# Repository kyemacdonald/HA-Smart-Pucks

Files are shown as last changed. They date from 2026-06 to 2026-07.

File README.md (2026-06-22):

# HA-Smart-Pucks
Home Assistant Smart Speakers based on ESP32s running ESPhome

<h2>Very much early stage. Use at own risk.</h2>

Smart Puck - HA Voice Assistant
* ESP32 S3 N16R8 / N8R2
* MAX98357A Class D Amplifier
* INMP441 Omnidirection Mic
* 5V WS2812 24LED ring (outer diameter 72mm)
* 2" 4 Ohm 3W speaker

Smart Speaker Box - HA Voice Assistant + SendSpin endpoint
* ESP32 S3 N16R8 
* MAX98357A Class D Amplifier
* INMP441 Omnidirection Mic
* 5V WS2812 8LED ring (outer diameter 27mm)
* 2" 4 Ohm 3W speaker
* PCM5102A DAC

Smart Puck

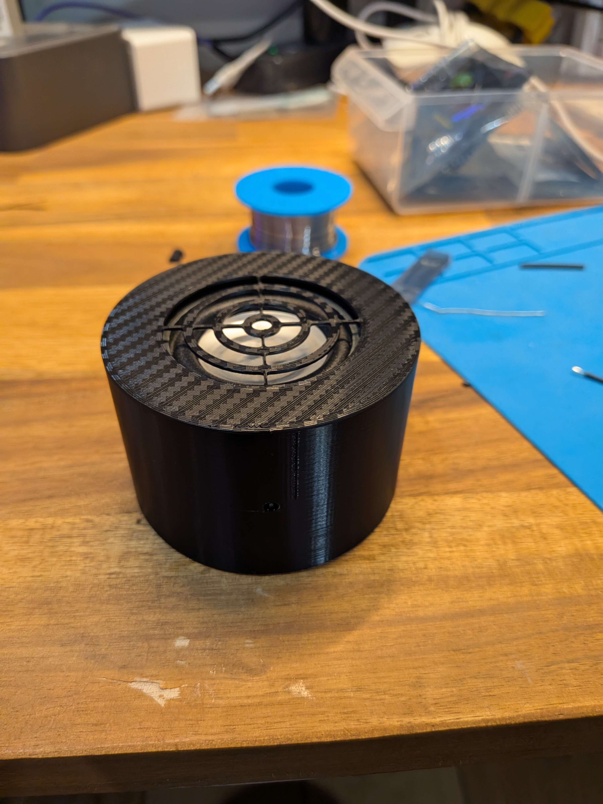
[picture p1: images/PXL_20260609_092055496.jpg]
Smart Puck


Smart Speaker Box

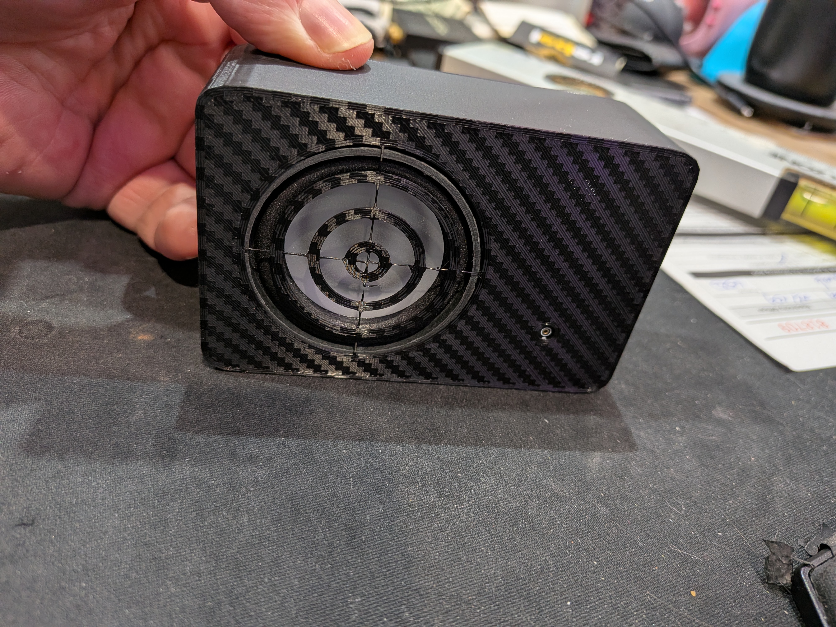
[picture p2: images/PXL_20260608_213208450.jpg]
Smart Speaker Box


Wiring Diagram for the Puck
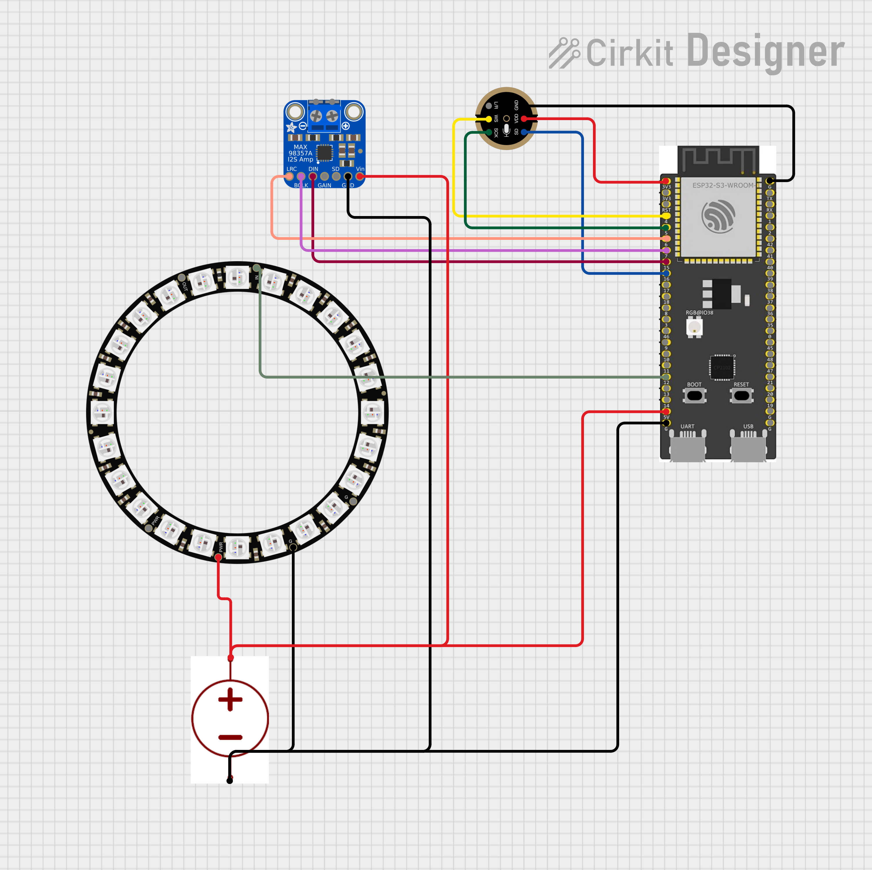
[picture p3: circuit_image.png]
Circuit Image


Wiring Diagram for the Box
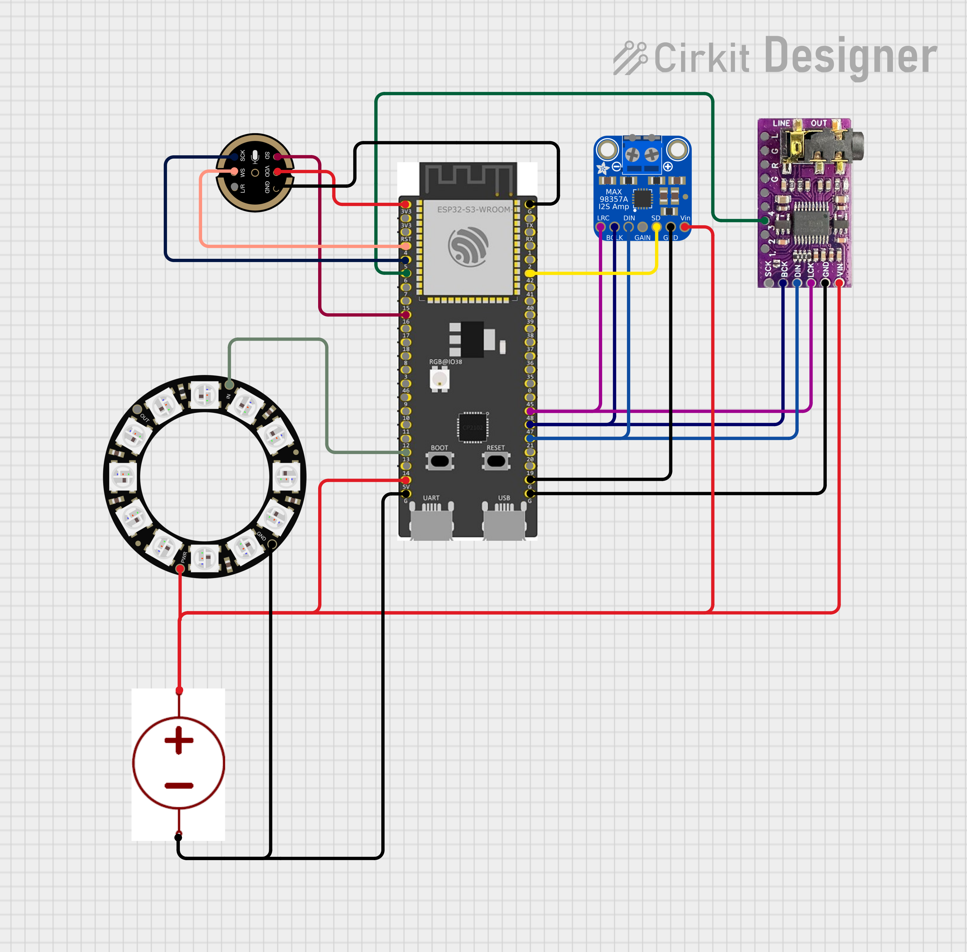
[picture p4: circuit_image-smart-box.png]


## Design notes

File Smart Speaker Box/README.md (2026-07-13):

Smart Speaker Box

Due to limitations in ESP hardware it is not possible to have more than 2 I2S devices connected.  One of these has to be the microphone and as a result only 1 channel can be used for DACs to allow output.

In order to get past this limitation both DACs are connected to the same pins on the ESP and they are individually muted depending on requirements.  Media playback goes via the PCM 3.5mm dac and TTS / announcements are routed via the MAX and internal 2" speaker.

There are some limitations to this setup.  Media is streamed to the device and uses the built in mixer system to queue playback.  TTS / Announce is given priority, which means it will interupt media playback and then media playback will resume.  There are however multiple buffers in the audio stream, their exact size is variable and there is no flag for when the buffers exhaust. As such you will get media output via the 2" internal speaker for a period before the TTS starts.  This ranges from sub 50ms to a second.  I have not been able to find a solution to this.  There is occasionally a small pop at the end of TTS before it switches back to the PCM.

The design setup is intended for 100% volume on both DACs.  This is a suitable volume level for the TTS output.  Adding it as a variable will likely happen in the future.

Finally SendSpin is very CPU intensive, you need to specify that the player receives PCM output from MusicAssistant otherwise CPU will get overwhelmed and you will lose wakeword detection.  There is occasional audio corruption when playback first starts, transient for up to 2 seconds.  This is all caused by CPU bind.  

13/7/26 Update
Added timer support.  You will need the timer_done.mp3 and place into an audio directory under esphome

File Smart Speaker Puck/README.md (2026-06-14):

STL files for the puck

Base and led support ring are universal.  

Lid with LED cutout plus diffuser is suitable for dark filament.

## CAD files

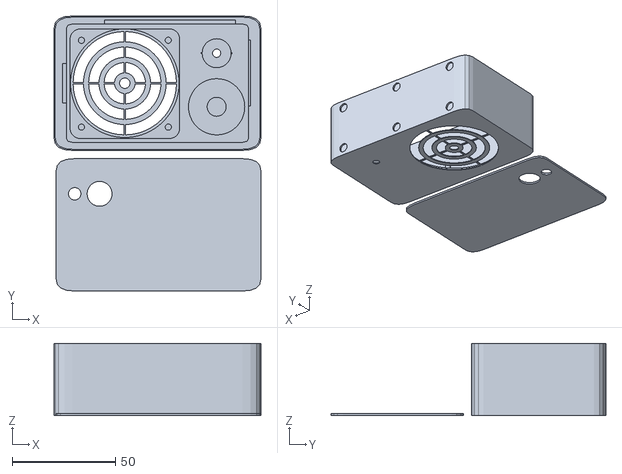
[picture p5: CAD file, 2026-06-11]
Smart Speaker Box/Smart Box.stl
100.0 x 133.0 x 35.0

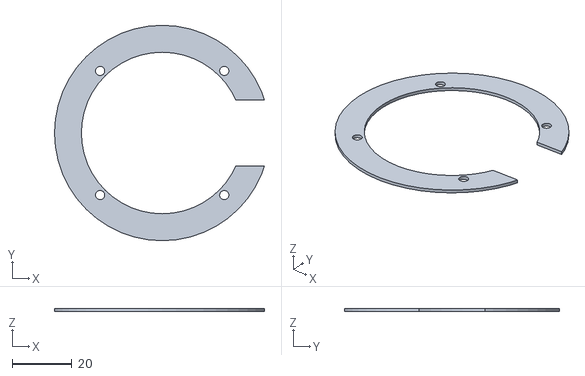
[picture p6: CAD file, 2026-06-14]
Smart Speaker Puck/Smark Puck LED support ring.stl
70.2 x 72.0 x 1.00

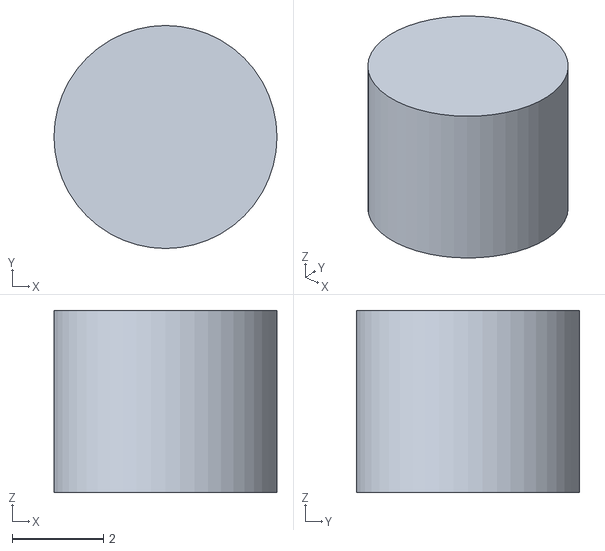
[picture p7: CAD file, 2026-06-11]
Smart Speaker Box/Feet.stl
4.90 x 4.90 x 4.00

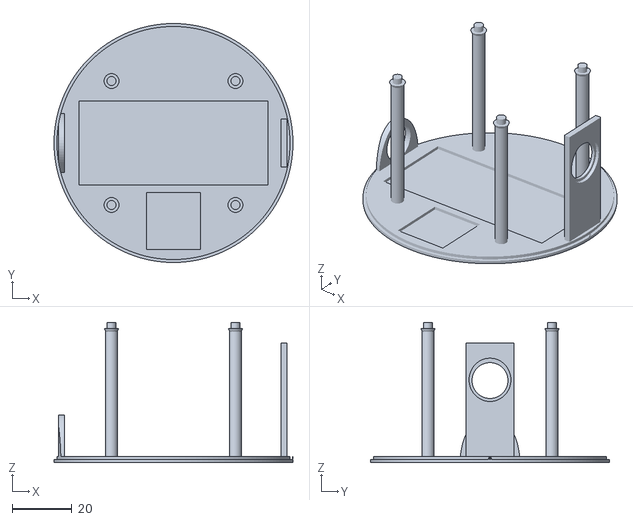
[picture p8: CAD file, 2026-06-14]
Smart Speaker Puck/Smart Puck V2.stl
80.0 x 80.0 x 47.0

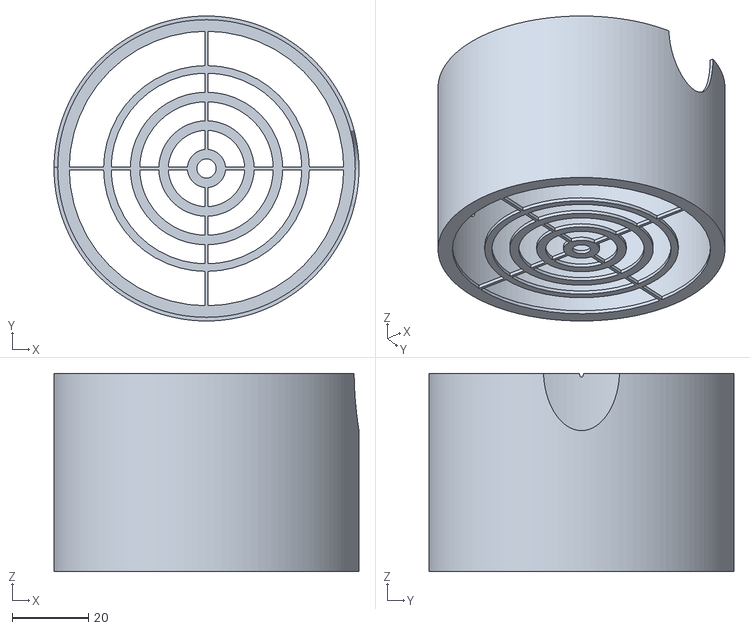
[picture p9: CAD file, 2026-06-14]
Smart Speaker Puck/Puck V2 Top.stl
80.0 x 80.0 x 52.0

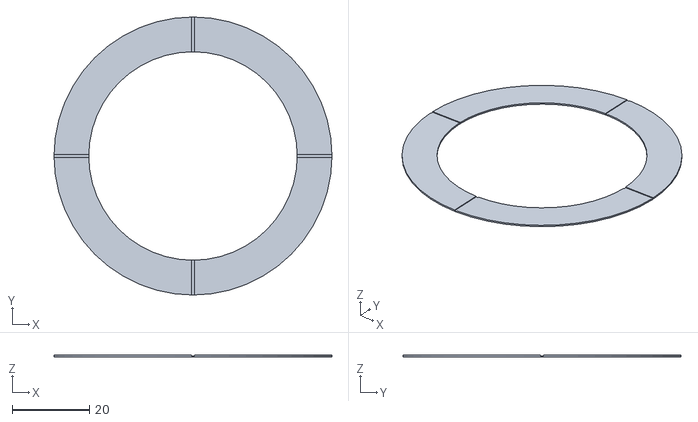
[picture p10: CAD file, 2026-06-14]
Smart Speaker Puck/Puck LED Diffuser.stl
72.0 x 72.0 x 0.4

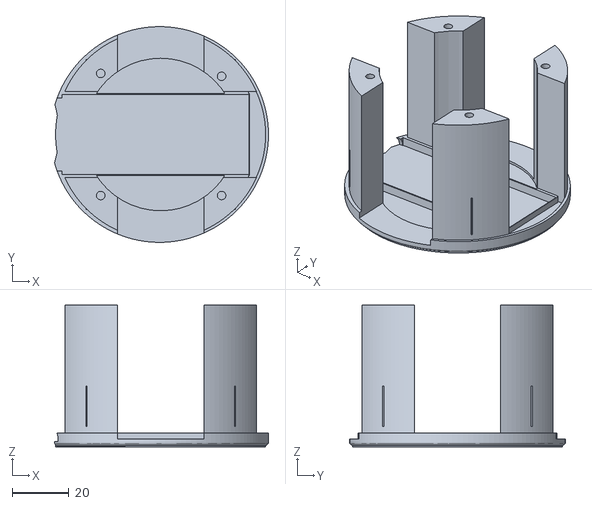
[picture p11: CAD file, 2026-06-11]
Smart Speaker Puck/Speaker puck base - tall.stl
75.4 x 76.0 x 50.0

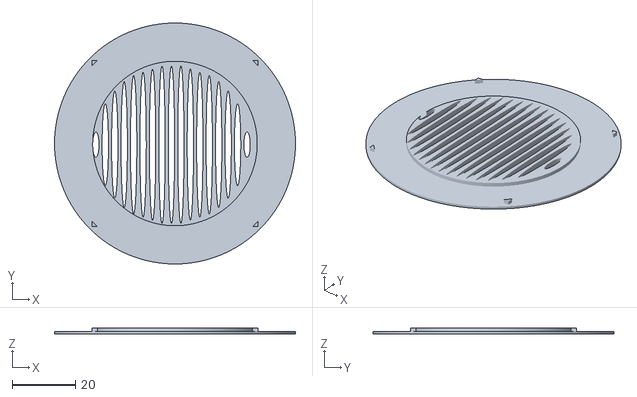
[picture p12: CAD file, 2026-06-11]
Smart Speaker Puck/Speaker-Puck-lid.stl
76.5 x 76.5 x 2.00

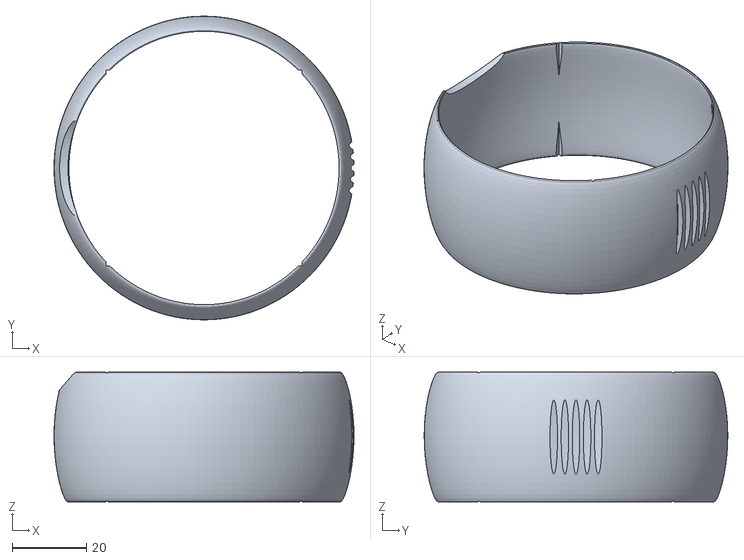
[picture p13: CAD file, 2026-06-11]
Smart Speaker Puck/Speaker-puck-walls.stl
81.0 x 82.0 x 35.0

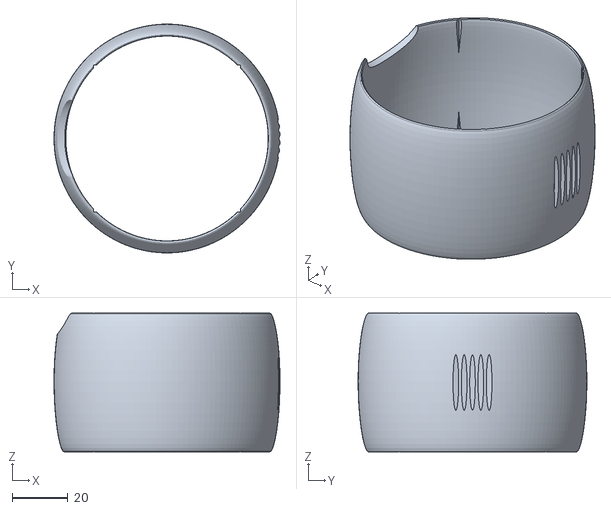
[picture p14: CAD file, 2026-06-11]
Smart Speaker Puck/Speaker puck walls - tall.stl
81.4 x 82.4 x 50.0

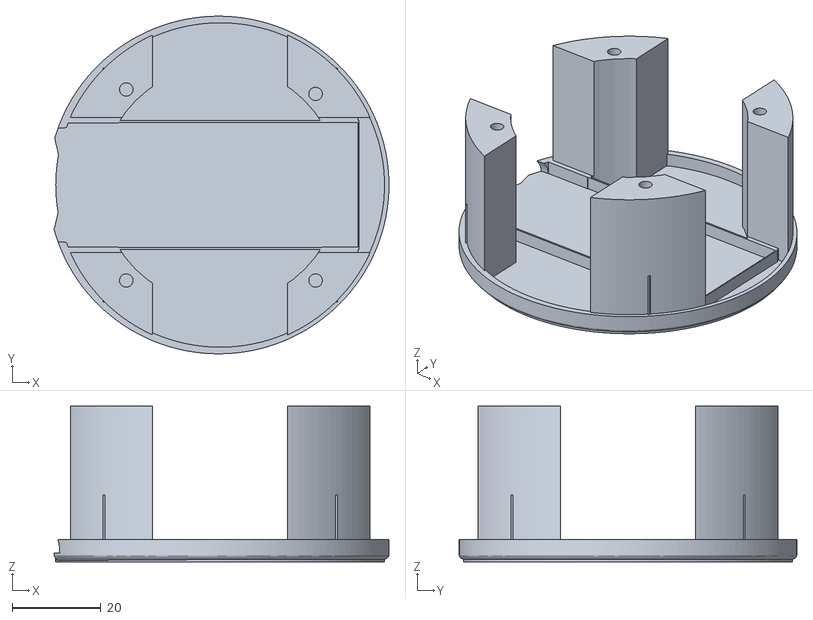
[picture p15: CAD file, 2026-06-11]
Smart Speaker Puck/Speaker-puck-base.stl
75.4 x 76.0 x 35.0

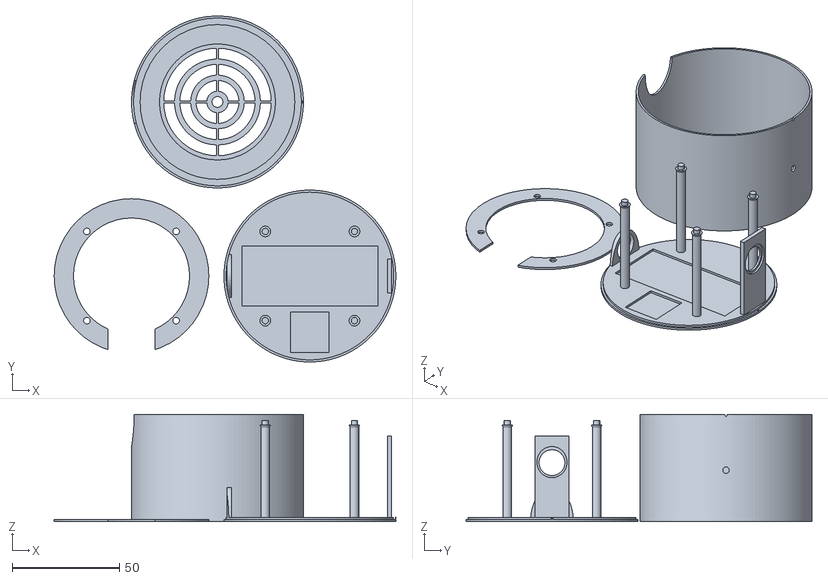
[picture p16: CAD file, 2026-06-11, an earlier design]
Smart Speaker Puck/old/v2/Smart Puck V2.stl
159.0 x 161.0 x 50.0

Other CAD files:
Smart Speaker Puck/Puck Lid LED cutout.stl

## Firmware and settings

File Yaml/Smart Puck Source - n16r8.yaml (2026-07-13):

esphome:
  name: esphome-web-cec770
  friendly_name: Smart Puck 1
  min_version: 2026.4.0
  name_add_mac_suffix: false

esp32:
  board: esp32-s3-devkitc-1
  variant: esp32s3
  flash_size: 16MB
  framework:
    type: esp-idf
    sdkconfig_options:
      CONFIG_ESP32_S3_BOX_BOARD: "y"
      CONFIG_ESP32S3_DEFAULT_CPU_FREQ_240: "y"
      CONFIG_ESP32S3_DATA_CACHE_64KB: "y"
      CONFIG_ESP32S3_DATA_CACHE_LINE_64B: "y"
      CONFIG_BT_ALLOCATION_FROM_SPIRAM_FIRST: "y"
      CONFIG_BT_BLE_DYNAMIC_ENV_MEMORY: "y"
      CONFIG_MBEDTLS_EXTERNAL_MEM_ALLOC: "y"
      CONFIG_MBEDTLS_SSL_PROTO_TLS1_3: "y"

psram:
  mode: octal
  speed: 80MHz

# Tracking variable to coordinate wake word restarts
globals:
  - id: tts_active
    type: bool
    restore_value: no
    initial_value: 'false'
  - id: active_timer_count
    type: int
    restore_value: no
    initial_value: '0'

logger:

api:
  on_client_connected:
    then:
      - delay: 500ms
      - light.turn_off: led_circle
      - media_player.volume_set: 1.0
      - micro_wake_word.start:
  on_client_disconnected:
    then:
      - voice_assistant.stop: 

# Using two separate named buses to prevent I2S hardware contention on the S3
i2s_audio:
  - id: mic_bus
    i2s_lrclk_pin: GPIO04
    i2s_bclk_pin: GPIO05

  - id: spk_bus
    i2s_lrclk_pin: GPIO06
    i2s_bclk_pin: GPIO07

microphone:
  - platform: i2s_audio
    id: mic
    i2s_audio_id: mic_bus
    adc_type: external        
    i2s_din_pin: GPIO16
    channel: right  
    pdm: false

speaker:
  - platform: i2s_audio
    id: big_speaker
    i2s_audio_id: spk_bus
    i2s_dout_pin: GPIO15
    dac_type: external
    channel: stereo
    sample_rate: 44100
    bits_per_sample: 16bit

  - platform: resampler
    id: voice_resampler
    output_speaker: big_speaker

media_player:
  - platform: speaker
    id: esps3_media_player
    name: VA Circle Media Player
    buffer_size: 65536
    volume_initial: 100%
    announcement_pipeline:
      speaker: voice_resampler
      format: MP3
    files:
      - id: alert_sound
        file: "audio/pop.mp3"
      - id: timer_done_sound
        file: "audio/timer_done.mp3"
    on_play:
      - switch.turn_on: amp_enable
      - light.turn_on:
          id: led_circle           
          brightness: 90%
          effect: "Talking Swirl"
    on_announcement:
      - switch.turn_on: amp_enable
      - light.turn_on:
          id: led_circle           
          brightness: 90%
          effect: "Talking Swirl"
    on_pause:            
      - switch.turn_off: amp_enable 
      - light.turn_off: led_circle
    on_idle:
      - switch.turn_off: amp_enable 
      - light.turn_off: led_circle
      # Safety-net: wait long enough for VA state machine to fully settle
      # (VA wind-down can take ~400ms after on_idle fires), then restart
      # MWW only if neither VA nor MWW is already running.
      - delay: 1500ms
      - if:
          condition:
            and:
              - not:
                  voice_assistant.is_running:
              - not:
                  micro_wake_word.is_running:
          then:
            - micro_wake_word.start:
      # If a timer is still active after this announcement finished (e.g. the
      # timer-done chime just played), restore the timer-pulse LED instead of
      # leaving it dark.
      - if:
          condition:
            and:
              - lambda: "return id(active_timer_count) > 0;"
              - not:
                  voice_assistant.is_running:
          then:
            - light.turn_on:
                id: led_circle
                brightness: 60%
                red: 100%
                green: 35%
                blue: 0%
                effect: "Slow Pulse"
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

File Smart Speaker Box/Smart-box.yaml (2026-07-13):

esphome:
  name: esphome-web-f82804
  friendly_name: Smart Box 1
  min_version: 2026.4.0
  name_add_mac_suffix: false

esp32:
  board: esp32-s3-devkitc-1
  variant: esp32s3
  flash_size: 16MB
  framework:
    type: esp-idf
    sdkconfig_options:
      CONFIG_ESP32S3_DEFAULT_CPU_FREQ_240: "y"
      CONFIG_ESP32S3_DATA_CACHE_64KB: "y"
      CONFIG_ESP32S3_DATA_CACHE_LINE_64B: "y"
      CONFIG_BT_ALLOCATION_FROM_SPIRAM_FIRST: "y"
      CONFIG_BT_BLE_DYNAMIC_ENV_MEMORY: "y"
      CONFIG_MBEDTLS_EXTERNAL_MEM_ALLOC: "y"
      CONFIG_MBEDTLS_SSL_PROTO_TLS1_3: "y"

psram:
  mode: octal
  speed: 80MHz

sendspin:
  id: sendspin_hub
  task_stack_in_psram: true

globals:
  - id: tts_active
    type: bool
    restore_value: no
    initial_value: "false"
  - id: pre_tts_volume
    type: float
    restore_value: no
    initial_value: "1.0"
  - id: volume_was_boosted
    type: bool
    restore_value: no
    initial_value: "false"
  - id: active_timer_count
    type: int
    restore_value: no
    initial_value: "0"

logger:
  logs:
    sendspin.player: ERROR # Suppress "Failed to send audio chunk" warnings

api:
  on_client_connected:
    then:
      - delay: 500ms
      - light.turn_off: led_circle
      - micro_wake_word.start:
  on_client_disconnected:
    then:
      - voice_assistant.stop:

# I2S bus layout:
#   mic_bus → INMP441 microphone          BCK: GPIO05  LRCK: GPIO04  DIN:  GPIO16
#   spk_bus → MAX98357A + PCM5102A        BCK: GPIO47  LRCK: GPIO48  DOUT: GPIO21
#             Both DACs share BCK/LRCK/DIN. Mute pins select which plays:
#               MAX98357A SD:   GPIO02 (amp_enable)  — TTS/announcements
#               PCM5102A  XSMT: GPIO06 (pcm_enable)  — media/music
i2s_audio:
  - id: mic_bus
    i2s_lrclk_pin: GPIO04
    i2s_bclk_pin: GPIO05

  - id: spk_bus
    i2s_lrclk_pin: GPIO48
    i2s_bclk_pin: GPIO47

microphone:
  - platform: i2s_audio
    id: mic
    i2s_audio_id: mic_bus
    adc_type: external
    i2s_din_pin: GPIO16
    channel: right
    pdm: false

speaker:
  - platform: i2s_audio
    id: spk_out
    i2s_audio_id: spk_bus
    i2s_dout_pin: GPIO21
    dac_type: external
    channel: stereo
    sample_rate: 44100
    bits_per_sample: 16bit
    buffer_duration: 50ms

  - platform: resampler
    id: spk_resampler
    output_speaker: spk_out
    sample_rate: 44100
    bits_per_sample: 16

  # Queue mode: announcement_source has priority, then media, then sendspin.
  - platform: mixer
    id: spk_mixer
    output_speaker: spk_resampler
    queue_mode: true
    source_speakers:
      - id: announcement_source
        buffer_duration: 20ms
      - id: media_spk_source
        buffer_duration: 20ms
      - id: sendspin_source
        buffer_duration: 20ms

media_source:
  - platform: sendspin
    id: sendspin_media_source
    sample_rate: 44100
    task_stack_in_psram: true
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

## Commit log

2026-06-11 Puck STL
    [Speaker puck base - tall.stl, Speaker puck walls - tall.stl, Speaker-Puck-lid.stl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]
2026-06-11 Update ESP32 S3 model information in README
2026-06-11 Add wiring diagram to README
    Added wiring diagram section with image reference.
2026-06-11 Add Smart Puck details and wiring diagram
    Added section for Smart Puck with image and wiring diagram.
2026-06-11 Update README with Smart Puck image and wiring diagram
    Added image for Smart Puck and wiring diagram.
2026-06-11 Update README with Smart Speaker Box image
    Added image for Smart Speaker Box and updated wiring diagram format.
2026-06-11 Add early stage warning to README
    Added a warning about the early stage of the project.
2026-06-14 Rename Smart Speaker Puck/Speaker puck base - tall.stl to Smart Speaker Puck/old/v1/Speaker puck base - tall.stl
    [Speaker puck base - tall.stl]
2026-06-14 Rename Smart Speaker Puck/Speaker puck walls - tall.stl to Smart Speaker Puck/old/v1/Speaker puck walls - tall.stl
    [Speaker puck walls - tall.stl]
2026-06-14 Rename Smart Speaker Puck/Speaker-Puck-lid.stl to Smart Speaker Puck/old/v1/Speaker-Puck-lid.stl
    [Speaker-Puck-lid.stl]
2026-06-14 Rename Smart Speaker Puck/Speaker-puck-base.stl to Smart Speaker Puck/old/v1/Speaker-puck-base.stl
    [Speaker-puck-base.stl]
2026-06-14 Rename Smart Speaker Puck/Speaker-puck-walls.stl to Smart Speaker Puck/old/v1/Speaker-puck-walls.stl
    [Speaker-puck-walls.stl]
2026-06-14 Rename Smart Speaker Puck/Smart Puck V2.stl to Smart Speaker Puck/old/v2/Smart Puck V2.stl
    [Smart Puck V2.stl]
2026-06-14 Add files via upload
    Updated STL design.
    Broke STL into separate components
    Variant of lid with cutout over leds and diffuser to suit.
    [Puck LED Diffuser.stl, Puck Lid LED cutout.stl, Puck V2 Top.stl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]
2026-06-14 Add README.md with STL file information
2026-06-21 Add wiring diagram for the Box
2026-07-13 Update README with timer support details
    Added timer support and instructions for audio file placement.
2026-07-13 added timer support
    added timer support, requires timer_done.mp3
2026-07-13 Implement timer support and active timer count
    Added timer support with active timer count management.
2026-07-13 Add active timer support and related features
